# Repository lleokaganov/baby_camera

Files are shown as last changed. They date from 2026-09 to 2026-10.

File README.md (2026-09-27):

# baby_camera

A baby monitor built from an AI-Thinker ESP32-CAM and a €2 I2S microphone.
Video and **sound**, in a printed case, on your own network, talking to nobody
else's server.

The point of this repository is not the code — it is short — but the half-dozen
things that silently do not work the way the tutorials say they do. Every one
of them cost an evening. They are all written down below.

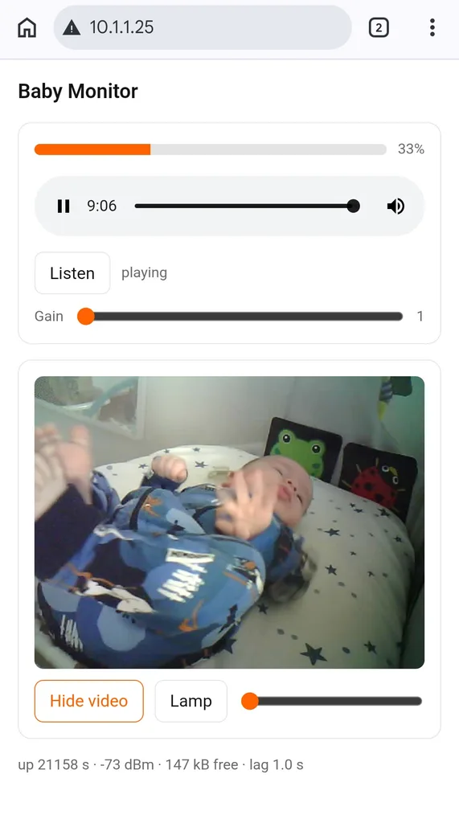
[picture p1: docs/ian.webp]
the page in use: level meter, player, live video


## What it does

| endpoint | what |
|---|---|
| `http://babycam/` | page: level meter, audio player, video toggle, lamp |
| `http://babycam:81/stream` | MJPEG video, only while somebody is watching |
| `http://babycam:82/audio` | endless WAV, running at all times |
| `http://babycam/level` | JSON: level, gain, uptime, RSSI, heap, diagnostics |
| `http://babycam/set?gain=N&lamp=N&chan=N&shift=N` | live tuning, no reflash |

Audio and video are **two independent streams**, on purpose. MJPEG cannot carry
sound at all — it is just concatenated JPEGs — and a baby monitor does not need
lip sync. It needs to be heard. Keeping them apart also means a stalled video
connection can never silence the microphone, and lets the ESP32's two cores each
do one job.

Sound runs continuously; video is off until you ask for it. You glance at the
picture occasionally and listen constantly, so the expensive stream is the one
that should be optional.

## Hardware

* **AI-Thinker ESP32-CAM** (sold with the marking `HW-297`, among others)
* **OV2640** camera, the standard 8×8 mm module
* **INMP441** I2S microphone module — pins labelled `GND VDD SO L/R WS SCK`.
  Sold both as the familiar rectangular breakout and as a small round board
  (marked `441` on the die); the pad names are identical on both.
* 5 V supply worth the name (see below)

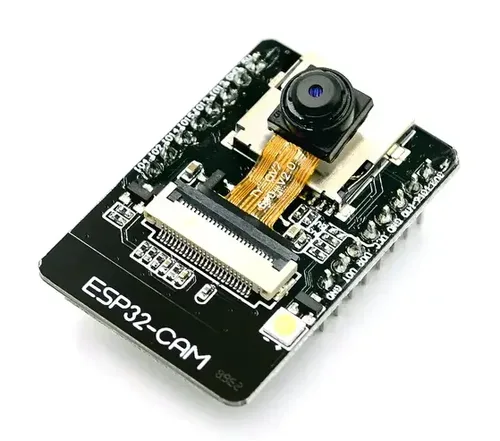
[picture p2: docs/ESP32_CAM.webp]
AI-Thinker ESP32-CAM board

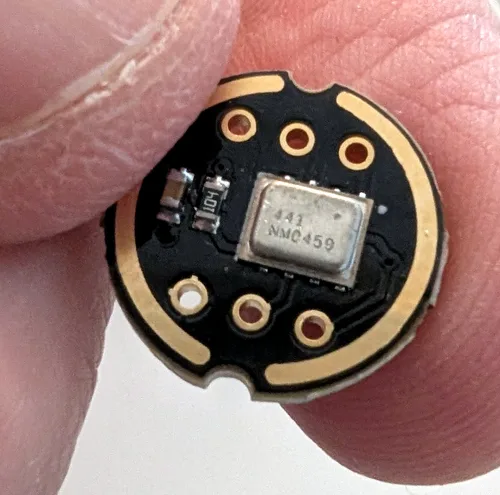
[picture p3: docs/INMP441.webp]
INMP441 microphone, round variant


Left: the ESP32-CAM, camera ribbon folded over the module. Right: the INMP441
in its round form, the die marked `441`. Both are a couple of euros apiece.

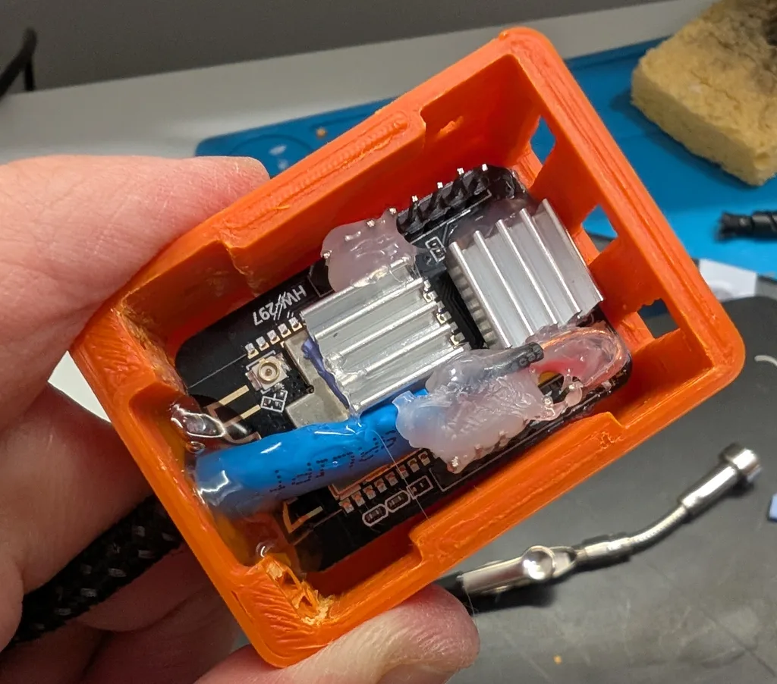
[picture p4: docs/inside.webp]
ESP32-CAM inside the printed case


The two heatsinks are not decorative. The board runs warm on a continuous
stream, which is also why the vented shell is the one to print.

### Wiring

| microphone | ESP32-CAM |
|---|---|
| `VDD` | **3V3** — not 5V, it is a 3.3 V part |
| `GND` | GND |
| `SCK` | IO14 |
| `WS` | IO15 |
| `SO` | **IO13** |
| `L/R` | GND |

Go by the **labels printed on the board**, not by counting pins: the header
order is not numerically sequential and counting is how you end up on the wrong
one.

`SO` must not go to **IO12**. That pin is the MTDI strap and sets the flash
voltage at reset; `SO` is driven by the microphone, so if it happens to be high
at power-up the board will not boot at all. IO13 has no strapping role.

IO13/14/15 belong to the microSD slot. The firmware never initialises the card,
so they are free. A live stream has no use for it.

## Six things that are not in the tutorials

**1. `ONLY_LEFT` is not the left channel.** With `L/R` tied to GND the datasheet
says the microphone speaks in the left slot, so `I2S_CHANNEL_FMT_ONLY_LEFT` is
the obvious choice. On the ESP32 receiver it yields a flat, perfect zero —
indistinguishable from an unconnected microphone. Use **`ONLY_RIGHT`**.

**2. The 24-bit sample is not left-justified.** Example code everywhere shifts
the 32-bit slot right by 16, assuming the data sits at the top. On this part it
sits in the low 24 bits, so the correct shift is **8**. Get this wrong and the
signal is real but three-quarters thrown away, quiet enough to look broken.

**3. The camera owns I2S0.** The `esp32-camera` driver uses it to clock the
parallel DVP bus. That is why so many people conclude sound is impossible on an
ESP32-CAM. The chip has two I2S blocks — put the microphone on **I2S1** and
nothing collides.

**4. `lru_purge_enable` is not optional.** `esp_http_server` has a socket limit.
Reach it and the server goes on *accepting* connections and closing them with no
response whatsoever: every endpoint looks stone dead while the board still
answers pings perfectly. Two forgotten browser tabs are enough. With LRU purge
on, old sockets are evicted and access is never lost.

**5. `<audio>` has no idea what "live" means.** It plays everything it received,
in order, and discards nothing. One network hiccup that later arrives as a burst
becomes *permanent* delay — an hour in, you are listening to twenty minutes ago.
The page therefore measures the gap between buffered and playing, shows it, and
jumps forward when it exceeds 1.5 s. On the device side the ring buffer **drops**
samples instead of queueing them, which is what bounds latency there. For a baby
monitor a momentary gap beats stale audio every time.

**6. A WAV header of `0xFFFFFFFF` stops some browsers.** It is the conventional
lie for an endless stream, but several browsers read it as −1, keep downloading
and never start decoding. `0x7FFFFFFF` is a lie they believe. And autoplay is
blocked until the page is interacted with, so there is an explicit Listen button
and a status line — a blocked stream must not look like a broken one.

## Powering it

The camera draws ~300 mA in bursts. A USB-serial dongle cannot supply that: the
board reboots forever with `Brownout detector was triggered` before it prints a
single line of its own. Give it 5 V from a real supply on the `5V` pin, keep the
ground common with the programmer, and add 470–1000 µF across 5V/GND at the
board.

The firmware disables the brownout detector, as is customary on these boards.
That silences *false* trips; it does nothing for a supply that genuinely sags,
and running under-volt risks corrupting flash. Fix the power, not the detector.

## Flashing

```bash
cd firmware
$EDITOR src/config.h        # your SSID and password go here
pio run -t upload
pio device monitor
```

Platform is pinned to `espressif32@6.5.0` (Arduino core 2.0.14) on purpose: it
still ships the legacy `driver/i2s.h`. Core 3.x replaced that API wholesale and
the rewrite would have to be re-verified against the camera driver for no gain.
The `huge_app` partition is required — camera plus three HTTP servers do not fit
the default app partition — which costs OTA.

### Getting into the bootloader

Hold `IO0` to GND, **then** power up. IO0 is sampled only at the rising edge of
reset, so pressing a BOOT button on a board that is already running does
nothing; that misunderstanding is the source of most "it will not flash" reports.

**A bad ESP32-CAM-MB shield fails in a way worth recognising.** Ours passed data
from the board to the PC — it happily printed the previous firmware's output —
but nothing in the other direction, and its DTR/RTS never reached EN or IO0.
esptool says only `No serial data received`, which it also says when no board is
attached at all. `tools/detect.sh` exists to tell those two apart: it listens
passively before it talks. A plain USB-UART dongle worked on the first attempt.

## Tools

```bash
tools/detect.sh            # what is on the port and which state it is in
tools/uart.sh [port] [baud]  # serial monitor; Ctrl-T timestamps, Ctrl-R reset
```

`detect.sh` distinguishes **running** (an application holds the UART),
**bootloader** (silent by design, answers SYNC) and **dead** — three states that
esptool reports with one identical error message.

## Case

Printed from [CasperJohansen's ESP32-CAM ball-joint case](https://www.thingiverse.com/thing:6106534)
(CC BY), which needs no supports and no modification. The three files we used
are copied into [`stl/`](stl/) — see the note there for print settings and
attribution. Parts used:

* `ESP32Cam-Caseantennahole+3vents.stl` — three vents matter, the board runs warm
  on a continuous stream
* `ESP32Cam-LensAdapter8x8module+smiley.stl` — for the stock 8×8 camera
* `ESP32Cam-MountingKit.stl` — wall plate, ball and knurled nut, if you are
  mounting to a wall or a shelf

Screws: 4× M2.5×4, 4× M2.5×5, 2× M2×5.

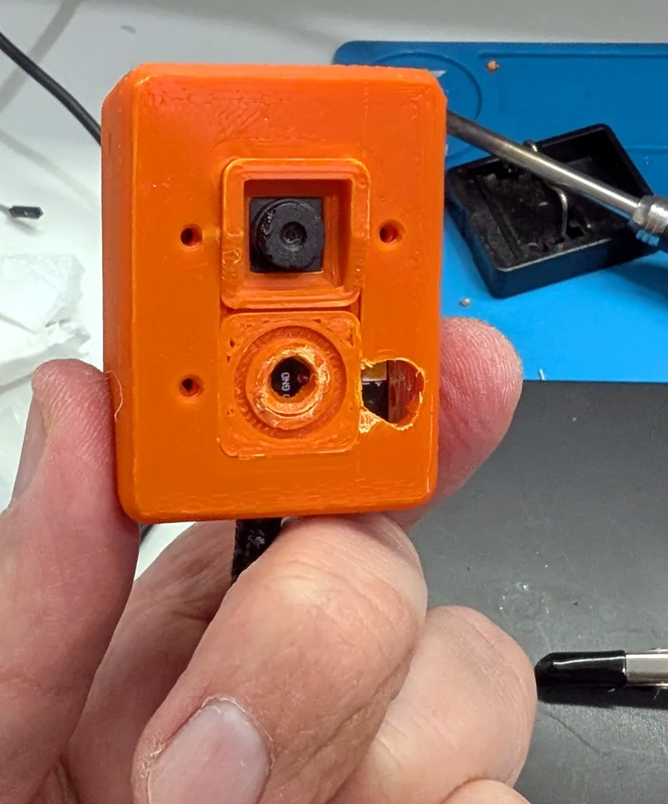
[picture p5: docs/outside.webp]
case front: lens, microphone port, LED slot

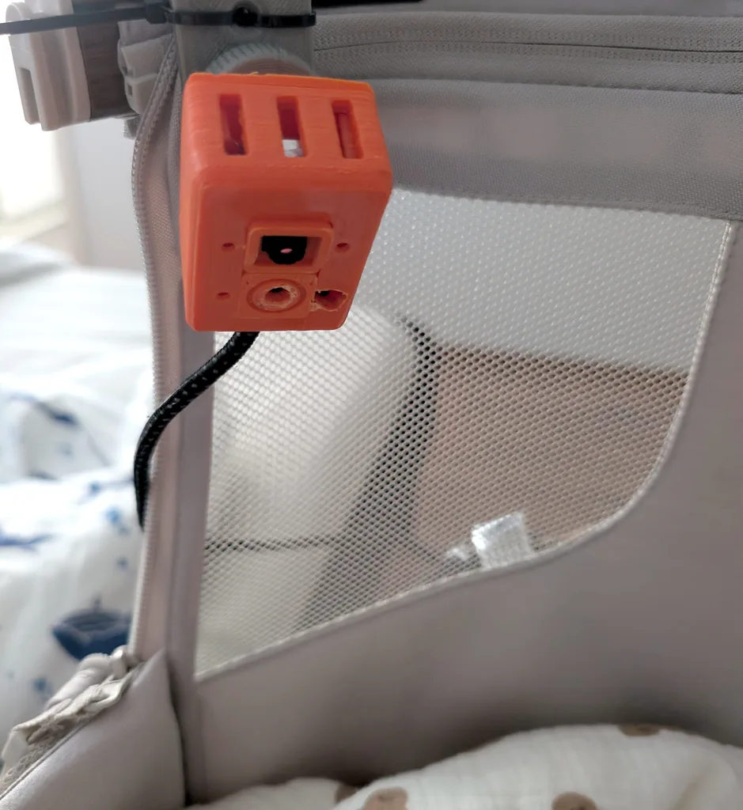
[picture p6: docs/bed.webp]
mounted on the cot rail


How it hangs is a question about your cot, not about this project. The ball
mount from the kit suits a wall; the one in the photo is a printed bracket and
two cable ties on the rail, aimed down into the cot.

Printed in HIPS for the case and SBS for the ball joint — the joint holds its
angle by friction and wants a plastic with some give. PLA is a poor choice for
anything that sits around a board that warms itself.

The vents double as the sound port, so no extra hole is needed. Note that the
INMP441 listens through a hole on its **underside**: glue that face to a wall and
it goes deaf.

## Limits

**One listener at a time — on the board.** The microphone task feeds a single
ring buffer and reading from it is destructive, so two listeners tear the
stream between them: not "the second one fails", but *both* get shredded. Two
browser tabs on one machine is enough to do it.

This is fixed outside the firmware. [`proxy/`](proxy/) holds `babyfan`, a
small Python daemon that keeps **one** connection to the board and fans it out
to as many viewers as you like — grandmothers included. It also closes that
connection whenever nobody is watching, which matters when the camera runs off
a power bank and is unwatched most of the day. No firmware change, so it works
on a board you have already sealed into its case.

**No recording.** Two unsynchronised streams are fine for listening and hopeless
for making a file you can watch later. That would mean RTSP, which on the
original ESP32 is a different project.

**No encryption, no authentication.** Anybody on your LAN can watch and listen.
Do not port-forward it.

## Licence

MIT for this code. The case model is CC BY by CasperJohansen — attribution is
above and stays there.

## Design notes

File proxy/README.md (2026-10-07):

# babyfan — one camera connection, many viewers

The board serves each stream from a single-threaded `esp_http_server`. A second
viewer does not get a second stream — the two tear the first one apart. This is
not a bug in our firmware; it is what an ESP32-CAM is.

`babyfan` sits in front of it, holds **one** upstream connection per stream and
fans the bytes out to everyone connected. Python, standard library only,
nothing to install.

It optimises exactly one thing: **while nobody is watching, nothing is read
from the camera at all.** Ours runs off a power bank and is unwatched about 99%
of the time, so the upstream opens on the first viewer and closes after the
last one leaves. Everything else is deliberately plain.

## Running it

```bash
sudo mkdir -p /opt/babyfan
sudo install -m 755 babyfan.py /opt/babyfan/
sudo install -m 644 babyfan.service /etc/systemd/system/
sudoedit /etc/systemd/system/babyfan.service   # set BABYFAN_CAMERA
sudo systemctl enable --now babyfan
journalctl -u babyfan -f    # who connected, and when the camera was released
```

It listens on `127.0.0.1:8090` by default and serves `/audio` and `/stream`.
Put it behind whatever already terminates TLS for you:

```nginx
upstream baby_video { server 127.0.0.1:8090; }
upstream baby_audio { server 127.0.0.1:8090; }

location = /stream {
    proxy_pass http://baby_video; proxy_http_version 1.1;
    proxy_set_header Connection ""; proxy_buffering off;
    proxy_read_timeout 24h; proxy_send_timeout 24h;
}
location = /audio  { ...the same, to baby_audio... }
```

Leave `/level` and `/set` pointing straight at the board: they are short
requests, there is nothing to fan out.

| variable | default | |
|---|---|---|
| `BABYFAN_CAMERA` | `10.1.1.25` | the board's address |
| `BABYFAN_PORT` | `8090` | pick another if something already has it |
| `BABYFAN_GRACE` | `8` | seconds to hold the camera after the last viewer |

## The bug you will hit if you write your own

`esp_http_server` streams with **`Transfer-Encoding: chunked`**. Reverse proxies
handle that for you, so it is invisible until you read the socket yourself —
and then the hex length markers land *inside* the media. The audio becomes
noise while the file size still looks perfectly reasonable, and the video
frames break while a naive `FFD8` count still finds them all. `babyfan` decodes
chunked itself.

## Details worth knowing

**The grace period is not an optimisation.** Phones lock their screens and drop
sockets constantly; without a delay the camera link would be torn down and
rebuilt every few seconds, which costs the board more than staying connected.

**A viewer whose socket backs up past 4 MB is dropped.** One stalled phone
would otherwise grow the buffer until the Pi runs out of memory.

**When the camera goes away, every viewer is dropped.** This is not tidiness,
it is the difference between a reconnect and a silent freeze. If the upstream
simply stops — the board reboots, the power bank hiccups — a viewer left
holding an open socket receives no error at all: the browser keeps the last
frame on screen and waits forever. Closing the socket is the only signal it
will act on. The page should reconnect on `error`, after a pause, so a
rebooting camera is not hammered while it comes back.

**Video viewers start at a part boundary.** Joining mid-frame would hand them
half a JPEG.

**Audio viewers get the WAV header replayed.** It is captured once from the
start of the upstream, so somebody joining an hour in still gets a valid file.

## Verified

Three simultaneous listeners, identical byte counts, **one** connection to the
camera. A listener joining five seconds in: valid WAV, 16 kHz / 16-bit / mono.
Two video viewers, intact frames. Ten seconds after everybody left: zero
connections to the camera.

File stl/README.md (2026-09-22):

# Case

These three files are **not ours**. They are part of
**[ESP32 Cam Case (Ball Joint mount)](https://www.thingiverse.com/thing:6106534)**
by **CasperJohansen**, published on Thingiverse under
**[CC BY 4.0](https://creativecommons.org/licenses/by/4.0/)**.

Copied here unmodified, because a link is a single point of failure and the
files are small. The full archive has more variants than the three below — a
sealed shell for outdoor use, plates for larger lenses, an arm that stands the
camera off the wall. Go to the original if none of these fit.

Note that the root `LICENSE` of this repository (MIT) covers the firmware and
the tools. It does not cover this directory.

| file | what |
|---|---|
| `ESP32Cam-Caseantennahole+3vents.stl` | the shell, both halves on one plate |
| `ESP32Cam-LensAdapter8x8module+smiley.stl` | front plate for the stock 8×8 mm camera |
| `ESP32Cam-MountingKit.stl` | wall plate, ball and knurled nut, all three on one plate |

Assembled, the shell is about 49 × 36 × 26 mm.

## Printing

No supports, nothing to rotate — print as they lie. The author used 0.12 mm
layers at 40% infill; ours came out fine at 0.2 mm with three perimeters, which
matters for the ball joint because it grips by friction.

Screws: 4× M2.5×4 for the lens plate, 4× M2.5×5 to close the shell, 2× M2×5 to
attach the ball. Find them before you start a two-hour print.

**Material.** Something that shrugs off warmth: the board is not cold when it
streams continuously. HIPS and ABS both work; PLA sits far too close to the
edge for a thing that lives over a cot. If your bed sticks well, print the ball
joint in a material with some give — it holds its angle by friction, and a
brittle one splits at the nut.

The vents double as the sound port, so do not fill them in.

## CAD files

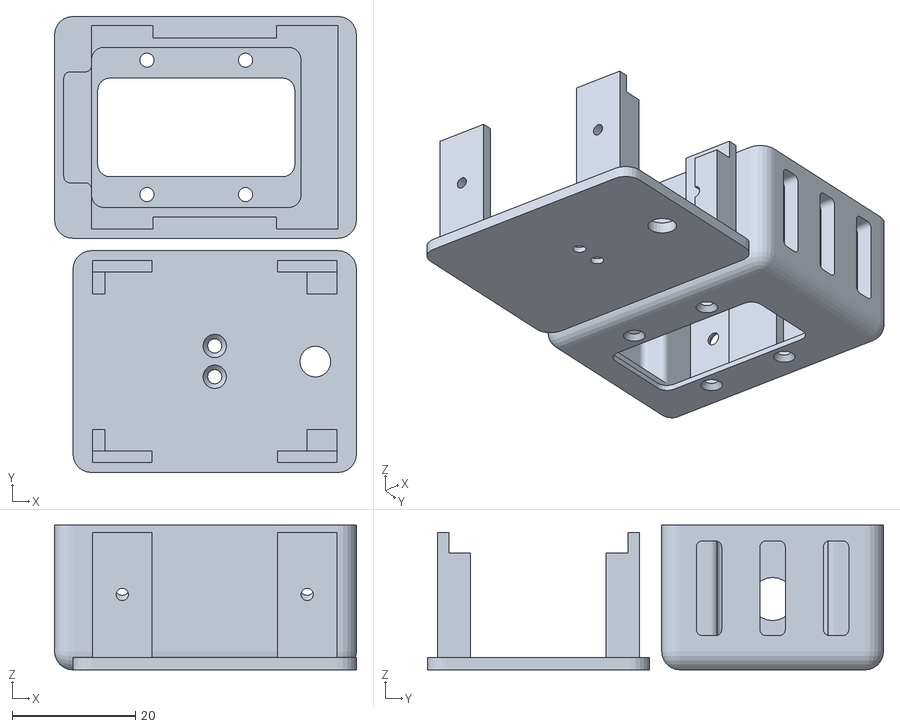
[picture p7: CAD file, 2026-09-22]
stl/ESP32Cam-Caseantennahole+3vents.stl
49.0 x 74.0 x 23.5

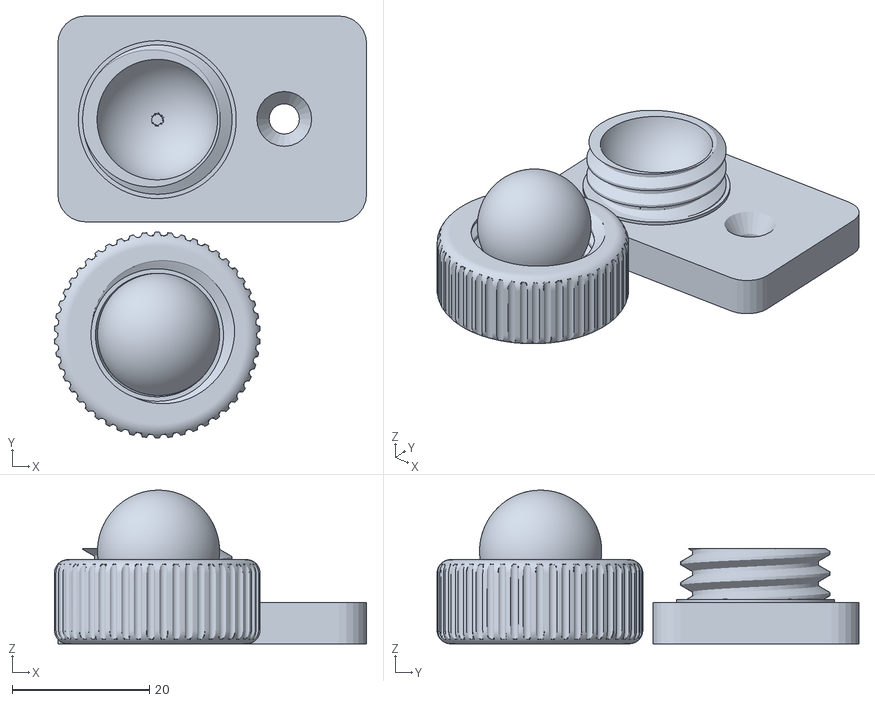
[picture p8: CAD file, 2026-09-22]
stl/ESP32Cam-MountingKit.stl
45.5 x 61.5 x 22.4

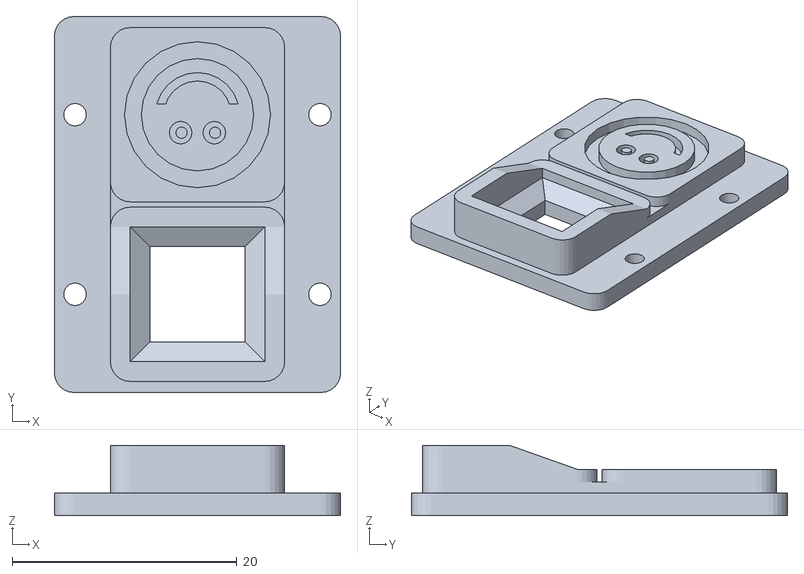
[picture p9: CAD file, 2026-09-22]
stl/ESP32Cam-LensAdapter8x8module+smiley.stl
25.5 x 33.5 x 6.25

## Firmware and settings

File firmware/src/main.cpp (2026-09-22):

// Baby monitor: AI-Thinker ESP32-CAM (HW-297) + INMP441 I2S microphone.
//
// Audio and video are deliberately two independent streams:
//   :82/audio  - endless WAV, always running
//   :81/stream - MJPEG, only while somebody is watching
//   :80/       - page, /level, /set
//
// MJPEG cannot carry sound at all (it is just concatenated JPEGs), and a baby
// monitor does not need lip sync - it needs to be heard. Keeping the two apart
// also means a stalled video connection cannot silence the microphone.
//
// The camera driver owns I2S0 (it clocks the parallel DVP bus), so the
// microphone runs on I2S1. They do not collide.

#include <Arduino.h>
#include <WiFi.h>
#include <math.h>

#include "esp_camera.h"
#include "esp_http_server.h"
#include "driver/i2s.h"
#include "soc/soc.h"
#include "soc/rtc_cntl_reg.h"
#include "freertos/stream_buffer.h"

#include "config.h"
#include "page.h"

// ----------------------------------------------------------------- camera pins
#define PWDN_GPIO_NUM   32
#define RESET_GPIO_NUM  -1
#define XCLK_GPIO_NUM    0
#define SIOD_GPIO_NUM   26
#define SIOC_GPIO_NUM   27
#define Y9_GPIO_NUM     35
#define Y8_GPIO_NUM     34
#define Y7_GPIO_NUM     39
#define Y6_GPIO_NUM     36
#define Y5_GPIO_NUM     21
#define Y4_GPIO_NUM     19
#define Y3_GPIO_NUM     18
#define Y2_GPIO_NUM      5
#define VSYNC_GPIO_NUM  25
#define HREF_GPIO_NUM   23
#define PCLK_GPIO_NUM   22

// ----------------------------------------------------------------- state
static StreamBufferHandle_t s_audio = nullptr;
static volatile float       s_level = 0.0f;   // 0..1 RMS of the last block
static volatile int         s_gain  = MIC_DEFAULT_GAIN;

// Diagnostics. "mic ok" at boot only proves the driver installed; it says
// nothing about whether the bus actually carries data. These separate the
// three ways silence can happen: i2s_read never returning (reads stays 0),
// the data line stuck at a constant (rawMin == rawMax), or a genuinely quiet
// microphone (raw swings, level near zero).
static volatile uint32_t s_reads   = 0;
static volatile int32_t  s_rawMin  = 0;
static volatile int32_t  s_rawMax  = 0;
static volatile uint32_t s_readErr = 0;

// Which half of the I2S frame to capture. Switchable at runtime because the
// ESP32 receiver is known to disagree with the datasheets about which slot
// "left" is, and reflashing once per guess is not a debugging method.
// 0 = ONLY_LEFT, 1 = ONLY_RIGHT.
static volatile int s_chan    = MIC_DEFAULT_CHAN;
static volatile int s_chanReq = -1;

// How far to shift the 32-bit slot down to 16 bits. 16 is correct for a
// 24-bit left-justified sample; SPH0645-class parts need a different value.
static volatile int s_shift = MIC_DEFAULT_SHIFT;

static httpd_handle_t s_ui = nullptr, s_video = nullptr, s_sound = nullptr;

// ----------------------------------------------------------------- WAV header
// The stream never ends, so the length fields are a lie either way. 0xFFFFFFFF
// is the obvious lie, but several browsers read it as -1 and refuse to start
// decoding while happily going on downloading -- a silent failure that looks
// exactly like a dead microphone. 0x7FFFFFFF is a lie they believe.
struct __attribute__((packed)) WavHeader {
  char     riff[4];
  uint32_t riffSize;
  char     wave[4];
  char     fmt[4];
  uint32_t fmtSize;
  uint16_t audioFormat;
  uint16_t numChannels;
  uint32_t sampleRate;
  uint32_t byteRate;
  uint16_t blockAlign;
  uint16_t bitsPerSample;
  char     data[4];
  uint32_t dataSize;
};

static void buildWavHeader(WavHeader *h) {
  memcpy(h->riff, "RIFF", 4);
  h->riffSize = 0x7FFFFFFF;
  memcpy(h->wave, "WAVE", 4);
  memcpy(h->fmt, "fmt ", 4);
  h->fmtSize       = 16;
  h->audioFormat   = 1;             // PCM
  h->numChannels   = 1;
  h->sampleRate    = MIC_SAMPLE_RATE;
  h->bitsPerSample = 16;
  h->blockAlign    = h->numChannels * h->bitsPerSample / 8;
  h->byteRate      = h->sampleRate * h->blockAlign;
  memcpy(h->data, "data", 4);
  h->dataSize = 0x7FFFFFFF;
}

// ----------------------------------------------------------------- microphone
static bool micInit(int chan) {
  i2s_config_t cfg = {};
  cfg.mode                 = (i2s_mode_t)(I2S_MODE_MASTER | I2S_MODE_RX);
  cfg.sample_rate          = MIC_SAMPLE_RATE;
  cfg.bits_per_sample      = I2S_BITS_PER_SAMPLE_32BIT;  // INMP441 sends 24 in 32
  cfg.channel_format       = chan ? I2S_CHANNEL_FMT_ONLY_RIGHT
                                  : I2S_CHANNEL_FMT_ONLY_LEFT;
  cfg.communication_format = I2S_COMM_FORMAT_STAND_I2S;
  cfg.intr_alloc_flags     = ESP_INTR_FLAG_LEVEL1;
  cfg.dma_buf_count        = 8;
  cfg.dma_buf_len          = MIC_BLOCK;
  cfg.use_apll             = false;
  cfg.tx_desc_auto_clear   = false;
  cfg.fixed_mclk           = 0;

  i2s_pin_config_t pins = {};
  pins.bck_io_num   = MIC_SCK_PIN;
  pins.ws_io_num    = MIC_WS_PIN;
  pins.data_out_num = I2S_PIN_NO_CHANGE;
  pins.data_in_num  = MIC_SD_PIN;

  if (i2s_driver_install(I2S_NUM_1, &cfg, 0, nullptr) != ESP_OK) return false;
  if (i2s_set_pin(I2S_NUM_1, &pins) != ESP_OK) return false;
  s_chan = chan;
  return true;
}

// Always running, whether anyone listens or not: that keeps the level meter
// live and means a new listener hears sound immediately instead of waiting
// for the DMA chain to fill.
static void micTask(void *) {
  static int32_t raw[MIC_BLOCK];
  static int16_t pcm[MIC_BLOCK];

  for (;;) {
    // Re-install from inside this task: doing it from the HTTP handler would
    // tear the driver out from under a concurrent i2s_read.
    if (s_chanReq >= 0) {
      int want = s_chanReq; s_chanReq = -1;
      i2s_driver_uninstall(I2S_NUM_1);
      micInit(want);
      s_reads = 0; s_readErr = 0; s_rawMin = 0; s_rawMax = 0;
    }

    size_t got = 0;
    // Bounded wait: portMAX_DELAY would hide a peripheral that never delivers,
    // and the whole point here is to be able to see that case.
    esp_err_t err = i2s_read(I2S_NUM_1, raw, sizeof(raw), &got, pdMS_TO_TICKS(500));
    const int n = (err == ESP_OK) ? (int)(got / sizeof(int32_t)) : 0;
    if (err != ESP_OK) s_readErr++;
    if (n <= 0) {
        // Both failure paths MUST sleep. i2s_read can return instantly when the
        // peripheral delivers nothing, and a bare `continue` then spins at task
        // priority forever -- which starved the HTTP servers sharing this core
        // and made the whole board look hung while it still answered pings.
        vTaskDelay(pdMS_TO_TICKS(50));
        continue;
    }
    s_reads++;

    int32_t lo = raw[0], hi = raw[0];
    for (int i = 1; i < n; i++) {
        if (raw[i] < lo) lo = raw[i];
        if (raw[i] > hi) hi = raw[i];
    }
    s_rawMin = lo; s_rawMax = hi;

    const int gain = s_gain;
    uint64_t acc = 0;
    for (int i = 0; i < n; i++) {
      // 24-bit sample sits left-justified in the slot; >>16 takes the top 16,
      // then software gain, because the INMP441 is quiet at conversational
      // distance and we want to hear breathing, not just crying.
      int32_t v = (raw[i] >> s_shift) * gain;
      if (v >  32767) v =  32767;
      if (v < -32768) v = -32768;
      pcm[i] = (int16_t)v;
      acc += (uint32_t)(v * v);
    }
    s_level = sqrtf((float)(acc / n)) / 32768.0f;

    // Never block: with no listener the buffer is full and samples are dropped
    // on purpose. Blocking here would stall the meter too.
    xStreamBufferSend(s_audio, pcm, n * sizeof(int16_t), 0);
  }
}

// ----------------------------------------------------------------- lamp
// GPIO4 drives the bright white flash LED. Dimmable rather than on/off: at full
// power it is a camera flash, far too harsh to point at a cot.
// LEDC channel 4, because the camera driver holds channel 0 for the XCLK.
#define LAMP_PIN      4
#define LAMP_CHANNEL  4
static volatile int s_lamp = 0;   // 0..255

static void lampInit() {
  ledcSetup(LAMP_CHANNEL, 5000, 8);
  ledcAttachPin(LAMP_PIN, LAMP_CHANNEL);
  ledcWrite(LAMP_CHANNEL, 0);
}

static void lampSet(int v) {
  if (v < 0) v = 0;
  if (v > 255) v = 255;
  s_lamp = v;
  ledcWrite(LAMP_CHANNEL, v);
}

// ----------------------------------------------------------------- handlers
static esp_err_t indexHandler(httpd_req_t *req) {
  httpd_resp_set_type(req, "text/html");
  return httpd_resp_send(req, INDEX_HTML, HTTPD_RESP_USE_STRLEN);
}

static esp_err_t levelHandler(httpd_req_t *req) {
  char buf[256];
  snprintf(buf, sizeof(buf),
           "{\"level\":%.4f,\"gain\":%d,\"uptime\":%lu,\"rssi\":%d,\"heap\":%u,"
           "\"reads\":%lu,\"readErr\":%lu,\"rawMin\":%ld,\"rawMax\":%ld,\"lamp\":%d,\"chan\":%d,\"shift\":%d}",
           s_level, s_gain, (unsigned long)(millis() / 1000),
           WiFi.RSSI(), (unsigned)ESP.getFreeHeap(),
           (unsigned long)s_reads, (unsigned long)s_readErr,
           (long)s_rawMin, (long)s_rawMax, s_lamp, s_chan, s_shift);
  httpd_resp_set_type(req, "application/json");
  httpd_resp_set_hdr(req, "Cache-Control", "no-store");
  return httpd_resp_send(req, buf, HTTPD_RESP_USE_STRLEN);
}

static esp_err_t setHandler(httpd_req_t *req) {
  char q[64], v[16];
  if (httpd_req_get_url_query_str(req, q, sizeof(q)) == ESP_OK &&
      httpd_query_key_value(q, "gain", v, sizeof(v)) == ESP_OK) {
    int g = atoi(v);
    if (g >= 1 && g <= 64) s_gain = g;
  }
  if (httpd_req_get_url_query_str(req, q, sizeof(q)) == ESP_OK &&
      httpd_query_key_value(q, "lamp", v, sizeof(v)) == ESP_OK) {
    lampSet(atoi(v));
  }
  if (httpd_req_get_url_query_str(req, q, sizeof(q)) == ESP_OK &&
      httpd_query_key_value(q, "chan", v, sizeof(v)) == ESP_OK) {
    s_chanReq = atoi(v) ? 1 : 0;
  }
  if (httpd_req_get_url_query_str(req, q, sizeof(q)) == ESP_OK &&
      httpd_query_key_value(q, "shift", v, sizeof(v)) == ESP_OK) {
    int sh = atoi(v);
    if (sh >= 8 && sh <= 24) s_shift = sh;
  }
  return httpd_resp_send(req, "ok", HTTPD_RESP_USE_STRLEN);
}

static esp_err_t audioHandler(httpd_req_t *req) {
  WavHeader h;
  buildWavHeader(&h);

  httpd_resp_set_type(req, "audio/wav");
  httpd_resp_set_hdr(req, "Cache-Control", "no-store");
  httpd_resp_set_hdr(req, "Access-Control-Allow-Origin", "*");
  if (httpd_resp_send_chunk(req, (const char *)&h, sizeof(h)) != ESP_OK) return ESP_FAIL;

  // Start from silence rather than from whatever has been sitting in the ring.
  xStreamBufferReset(s_audio);

  uint8_t buf[1024];
  for (;;) {
    size_t n = xStreamBufferReceive(s_audio, buf, sizeof(buf), pdMS_TO_TICKS(300));
    if (n == 0) {
        // Send real silence rather than looping. A handler that never writes
        // never learns that the client has gone, and since this server runs
        // one request at a time it would hold the port shut for everybody.
        memset(buf, 0, 256);
        n = 256;
    }
    if (httpd_resp_send_chunk(req, (const char *)buf, n) != ESP_OK) break;
  }
  return ESP_OK;
}

#define BOUNDARY "frame"
static esp_err_t streamHandler(httpd_req_t *req) {
  httpd_resp_set_type(req, "multipart/x-mixed-replace;boundary=" BOUNDARY);
  httpd_resp_set_hdr(req, "Access-Control-Allow-Origin", "*");

  char part[80];
  for (;;) {
    camera_fb_t *fb = esp_camera_fb_get();
    if (!fb) { vTaskDelay(pdMS_TO_TICKS(50)); continue; }

    int len = snprintf(part, sizeof(part),
                       "\r\n--" BOUNDARY "\r\nContent-Type: image/jpeg\r\n"
                       "Content-Length: %u\r\n\r\n", (unsigned)fb->len);
    esp_err_t r = httpd_resp_send_chunk(req, part, len);
    if (r == ESP_OK) r = httpd_resp_send_chunk(req, (const char *)fb->buf, fb->len);
    esp_camera_fb_return(fb);
    if (r != ESP_OK) break;
  }
  return ESP_OK;
}

// ----------------------------------------------------------------- servers
// Three servers, not one. esp_http_server processes requests serially in a
// single task, so one endless handler would block every other endpoint.
// Each instance also needs its own ctrl_port - sharing it silently fails.
//
// lru_purge_enable is not optional here. Without it, once max_open_sockets is
// reached the server accepts further connections and closes them with no
// response at all -- every endpoint appears dead while the board still pings
// happily. A couple of forgotten browser tabs are enough to reach that state,
// because the page holds an audio stream and polls four times a second.
static void startServers() {
  httpd_uri_t uIndex = {"/",      HTTP_GET, indexHandler,  nullptr};
  httpd_uri_t uLevel = {"/level", HTTP_GET, levelHandler,  nullptr};
  httpd_uri_t uSet   = {"/set",   HTTP_GET, setHandler,    nullptr};
  httpd_uri_t uSnd   = {"/audio", HTTP_GET, audioHandler,  nullptr};
  httpd_uri_t uVid   = {"/stream",HTTP_GET, streamHandler, nullptr};

  httpd_config_t c = HTTPD_DEFAULT_CONFIG();
  c.server_port = 80; c.ctrl_port = 32768; c.max_uri_handlers = 4;
  c.lru_purge_enable = true; c.max_open_sockets = 7;
  if (httpd_start(&s_ui, &c) == ESP_OK) {
    httpd_register_uri_handler(s_ui, &uIndex);
    httpd_register_uri_handler(s_ui, &uLevel);
    httpd_register_uri_handler(s_ui, &uSet);
  }

  c = HTTPD_DEFAULT_CONFIG();
  c.server_port = 81; c.ctrl_port = 32769;
  c.lru_purge_enable = true; c.max_open_sockets = 3;
  if (httpd_start(&s_video, &c) == ESP_OK) httpd_register_uri_handler(s_video, &uVid);

  c = HTTPD_DEFAULT_CONFIG();
  c.server_port = 82; c.ctrl_port = 32770;
  c.lru_purge_enable = true; c.max_open_sockets = 3;
  if (httpd_start(&s_sound, &c) == ESP_OK) httpd_register_uri_handler(s_sound, &uSnd);
}

// ----------------------------------------------------------------- setup
static bool cameraInit() {
  camera_config_t c = {};
  c.ledc_channel = LEDC_CHANNEL_0;
  c.ledc_timer   = LEDC_TIMER_0;
  c.pin_d0 = Y2_GPIO_NUM;  c.pin_d1 = Y3_GPIO_NUM;
  c.pin_d2 = Y4_GPIO_NUM;  c.pin_d3 = Y5_GPIO_NUM;
  c.pin_d4 = Y6_GPIO_NUM;  c.pin_d5 = Y7_GPIO_NUM;
  c.pin_d6 = Y8_GPIO_NUM;  c.pin_d7 = Y9_GPIO_NUM;
  c.pin_xclk = XCLK_GPIO_NUM;   c.pin_pclk  = PCLK_GPIO_NUM;
  c.pin_vsync = VSYNC_GPIO_NUM; c.pin_href  = HREF_GPIO_NUM;
  c.pin_sccb_sda = SIOD_GPIO_NUM; c.pin_sccb_scl = SIOC_GPIO_NUM;
  c.pin_pwdn = PWDN_GPIO_NUM;   c.pin_reset = RESET_GPIO_NUM;
  c.xclk_freq_hz = 20000000;
  c.pixel_format = PIXFORMAT_JPEG;
  c.frame_size   = CAM_FRAME_SIZE;
  c.jpeg_quality = CAM_JPEG_QUALITY;
  c.fb_count     = psramFound() ? 2 : 1;
  c.fb_location  = psramFound() ? CAMERA_FB_IN_PSRAM : CAMERA_FB_IN_DRAM;
  // Always hand out the newest frame; a queue of stale frames only adds lag.
  c.grab_mode    = CAMERA_GRAB_LATEST;
  return esp_camera_init(&c) == ESP_OK;
}

void setup() {
  // The 5 V regulator on these boards sags when the camera and WiFi start
  // together, and the brownout detector reboots a board that would otherwise
  // run fine. Standard practice on ESP32-CAM.
  WRITE_PERI_REG(RTC_CNTL_BROWN_OUT_REG, 0);

  Serial.begin(115200);
  Serial.setDebugOutput(false);
  Serial.println("\n[babycam] boot");

  lampInit();

  if (!cameraInit()) Serial.println("[babycam] camera init FAILED");
  else               Serial.println("[babycam] camera ok");

  s_audio = xStreamBufferCreate(AUDIO_RING_BYTES, sizeof(int16_t) * MIC_BLOCK);
  if (!micInit(MIC_DEFAULT_CHAN)) Serial.println("[babycam] mic init FAILED");
  else                 Serial.println("[babycam] mic ok");

  // Microphone on core 1, away from the WiFi/LwIP stack on core 0.
  xTaskCreatePinnedToCore(micTask, "mic", 4096, nullptr, 5, nullptr, 1);

  WiFi.setHostname(HOSTNAME);
  WiFi.mode(WIFI_STA);
  WiFi.begin(WIFI_SSID, WIFI_PASSWORD);
  WiFi.setSleep(false);   // power saving adds seconds of latency to a stream

  Serial.print("[babycam] wifi");
  while (WiFi.status() != WL_CONNECTED) { delay(400); Serial.print('.'); }
  Serial.printf("\n[babycam] http://%s/\n", WiFi.localIP().toString().c_str());

  startServers();
}

void loop() {
  // Everything runs in tasks. Reconnect if the access point drops.
  if (WiFi.status() != WL_CONNECTED) {
    Serial.println("[babycam] wifi lost, reconnecting");
    WiFi.reconnect();
    delay(2000);
  }
  delay(1000);
}

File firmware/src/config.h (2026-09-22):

#pragma once

// ---------------------------------------------------------------- network
// Example values -- replace with your own before flashing.
// The ESP32 is 2.4 GHz only: it cannot see a 5 GHz network at all.
#define WIFI_SSID      "lleo"
#define WIFI_PASSWORD  "MyPassw123"
#define HOSTNAME       "babycam"

// ---------------------------------------------------------------- microphone
// INMP441 on I2S1. I2S0 is not available: the camera driver uses it to clock
// the parallel DVP bus.
//
// All three pins belong to the microSD slot, which we simply never initialise.
// SD is useless for a live stream anyway.
//
// SD (data out of the mic) MUST NOT go to GPIO12. That pin is the MTDI strap
// and sets the flash voltage at reset; a microphone driving it high at
// power-up stops the board from booting. GPIO13 has no strapping function.
#define MIC_SCK_PIN    14
#define MIC_WS_PIN     15
#define MIC_SD_PIN     13
// Tie the module's L/R pad to GND -> the mic speaks in the left slot.

#define MIC_SAMPLE_RATE   16000   // plenty for a voice; halves the bandwidth
#define MIC_BLOCK          256    // samples per I2S read
#define MIC_DEFAULT_GAIN     2    // software gain, adjustable at runtime

// Which half of the I2S frame carries the data, and how far to shift the
// 32-bit slot down to 16 bits. Both were found by measurement, not by reading
// datasheets, and both differ from the obvious answer:
//
//   chan = 1 (ONLY_RIGHT) even though L/R is tied to GND. The ESP32 receiver
//   disagrees with the microphone's datasheet about which slot is "left";
//   ONLY_LEFT yields a flat zero, which is indistinguishable from an
//   unconnected microphone and cost an evening to find.
//
//   shift = 8. The 24-bit sample is NOT left-justified in the 32-bit slot as
//   the usual example code assumes; it sits in the low 24 bits. Shifting by 16
//   throws away three quarters of the signal and leaves it inaudibly quiet.
//
// Measured with these values: peak 30012/32767, RMS 17.4%, no clipping.
#define MIC_DEFAULT_CHAN     1
#define MIC_DEFAULT_SHIFT    8

// Ring capacity between the microphone task and the HTTP listener.
// ~0.25 s at 16 kHz mono 16-bit. Deliberately small: this buffer is a shock
// absorber, not a store. When it overflows the samples are DROPPED rather than
// queued, which is what keeps latency bounded on the device side - a growing
// queue would turn into permanent delay, and for a baby monitor stale audio is
// worse than a momentary gap.
#define AUDIO_RING_BYTES   8192

// ---------------------------------------------------------------- camera
#define CAM_FRAME_SIZE   FRAMESIZE_VGA
#define CAM_JPEG_QUALITY 12        // lower value = better picture, more bytes

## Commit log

2026-09-22 Baby monitor on ESP32-CAM with I2S sound
    Two independent streams: MJPEG video on :81 and an endless WAV on :82.
    MJPEG cannot carry audio, and a baby monitor needs to be heard rather than
    lip-synced, so they are kept apart -- which also survives one of them stalling.
    Documents the six things that silently differ from every tutorial: ONLY_LEFT
    capturing nothing, the 24-bit sample not being left-justified, the camera
    owning I2S0, lru_purge_enable being mandatory, <audio> accumulating latency
    forever, and 0xFFFFFFFF in a WAV header stopping some browsers.
    [config.h, main.cpp]
2026-09-22 Add photographs of the finished device
    Four shots: the page in use, the board inside the printed shell, the case
    front with lens and microphone port, and the camera on the cot rail.
    Also corrects two claims. The mount shown is a printed bracket with cable
    ties, not the ball mount from the case archive -- how it hangs depends on
    the cot, so the kit is listed as an option rather than a requirement. And
    the INMP441 ships as a round board as well as the usual rectangular one,
    which is worth saying before someone decides the wiring table is not about
    their part.
2026-09-22 Add photographs of the two components
    The ESP32-CAM board and the INMP441 in its round form, so the hardware list
    is recognisable at a glance rather than a list of part numbers.
2026-09-22 Vendor the three STL files we actually print
    CasperJohansen's case is CC BY, which permits redistribution with
    attribution, so the files can live here rather than behind a link that has
    already shown itself willing to return 'removed' on a good day.
    stl/README.md carries the attribution, the print settings and the screw
    list, and states plainly that the repository's MIT licence does not reach
    into that directory.
    [ESP32Cam-Caseantennahole+3vents.stl, ESP32Cam-LensAdapter8x8module+smiley.stl, ESP32Cam-MountingKit.stl]
2026-09-27 Add babyfan: one camera connection, many viewers
    The board serves each stream from a single-threaded esp_http_server, so a
    second viewer does not get a second stream -- the two tear the first one
    apart. babyfan holds one upstream connection per stream and fans the bytes
    out, which removes the limitation without touching firmware. That matters
    here: the camera is already assembled into its case.
    It optimises one thing only: nothing is read from the camera while nobody is
    watching. Ours runs off a power bank and is unwatched almost all of the time.
    Documents the trap that cost an evening: esp_http_server streams with
    Transfer-Encoding chunked, which reverse proxies hide from you. Read the
    so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
2026-10-07 babyfan: drop viewers when the camera goes away
    A stream that simply stops is invisible to an MJPEG viewer: no error fires,
    the browser keeps the last frame and waits forever. The proxy was leaving
    viewers holding a dead socket whenever the upstream ended, so a camera reboot
    turned into a permanent freeze that looked like a proxy bug.
    Closing the viewers is what turns that silence into a reconnect.
    Verified against a stand-in camera that hangs up mid-stream: the viewer is
    released at the moment the upstream dies instead of waiting out its own
    timeout.
